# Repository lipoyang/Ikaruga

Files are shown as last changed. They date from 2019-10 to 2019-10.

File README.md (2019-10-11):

# 斑鳩ボード
## 概要
斑鳩ボードは、Nordic nRF52832搭載のBLEマイコンボードです。 

## 仕様
* BLEマイコンnRF52832搭載 (Bluetooth 4.2 / ARM Cortex-M4F)
* 技適取得済みnRF52832モジュール Liard BL652を使用
* Arduino Pro Miniピン互換 (GR-KURUMIやGR-CITRUSとも共通)
* nRF52-DKの開発環境（mbedやnRF5 SDK）で開発
* nRF52-DK や BLE Nano V2のDAPLinkボードをアダプタとして使う
* 300mAのLDO、3色のLED、32.768kHzサブクロック、リセットスイッチを搭載

## ピン配置
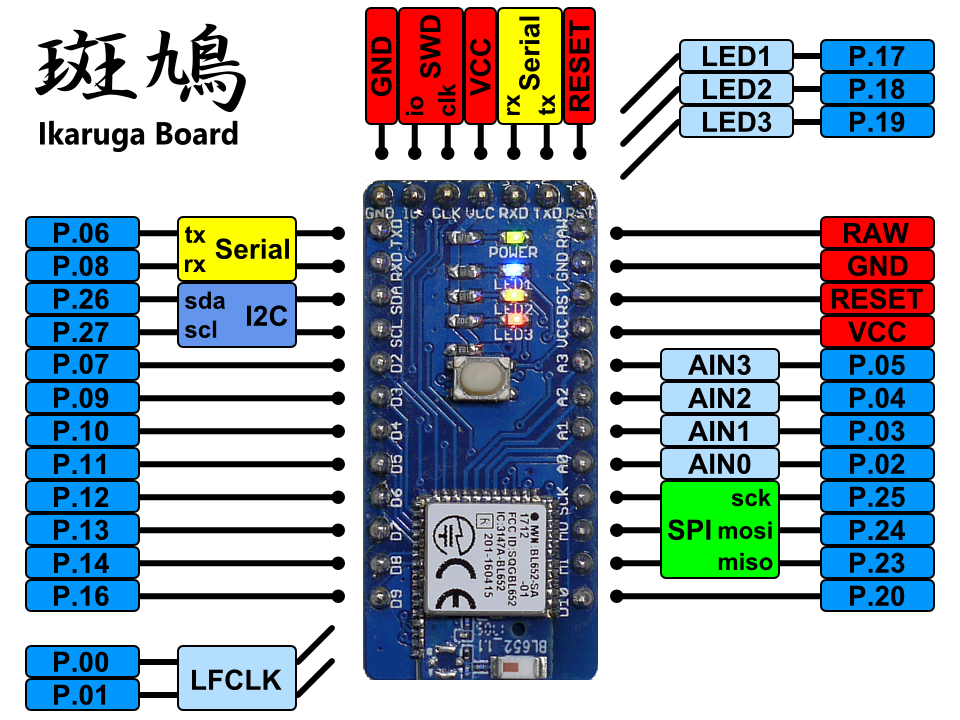
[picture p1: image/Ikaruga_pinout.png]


## 開発環境 (mbed)
* mbed Compiperのプラットフォーム選択でNordic nRF52-DKを選びます。
* BLE Nano V2のDAPLinkボードを使う場合、斑鳩を下図ように結線します。
* あとは、ふつうにmbedの要領で開発します。
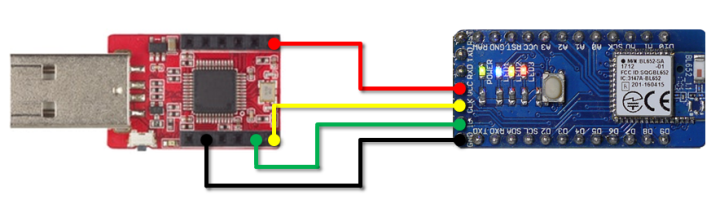
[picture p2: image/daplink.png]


## nRF52-DKをアダプタに使う場合
最低限、結線が必要なのは以下の4本です。

* GND DETECT　→　ターゲットのGNDに接続
* VTG　→　ターゲットの電源電圧(VDD_nRF)に接続
* SWD CLK　→　ターゲットのSWDCLKに接続
* SWD IO　→　ターゲットのSWDIOに接続

加えて、nRF52-DKボードから斑鳩ボードに給電する場合には以下の2本を結線します。

* GND　→　ターゲットのGNDに接続
* VDD　→　ターゲットの電源電圧(VDD_nRF)に接続
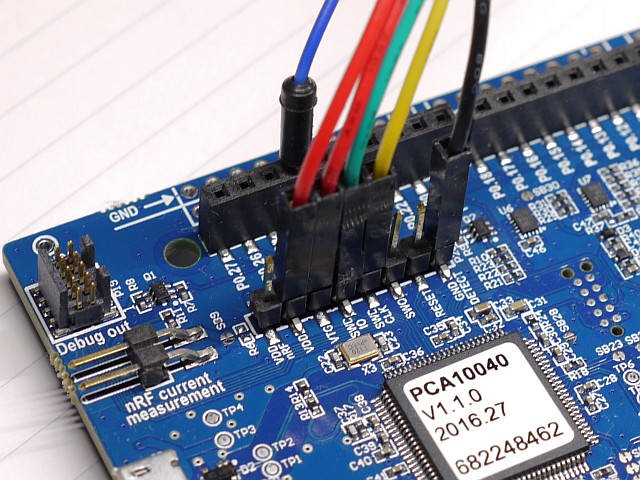
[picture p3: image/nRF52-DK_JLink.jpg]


## Ｌチカ (mbed)
```C
#include "mbed.h"

DigitalOut myled1(LED1); // Blue
DigitalOut myled2(LED2); // Yellow
DigitalOut myled3(LED3); // Red

int main() {
    while(1) {
        myled1 = 1;
        wait(0.5);
        myled2 = 1;
        wait(0.5);
        myled3 = 1;
        wait(0.5);
        myled1 = 0;
        wait(0.5);
        myled2 = 0;
        wait(0.5);
        myled3 = 0;
        wait(0.5);
    }
}
```

## ファイル一覧
* hard/Ikaruga/
	* Ikaruga.sch/brd: 回路/基板設計データ(Eagle形式)
	* Ikaruta.pdf: 回路図(PDF)
	* Ikaruga_BOM.xlsx: BOMリスト(Excel形式)
	* Ikaruga.GBL/GBO/GBP/GBS/GML/GTL/GTO/GTP/GTS/TXT: ガーバデータ
* LICENSE: Apache Licence 2.0です。
	* ただし、回路/基板設計は、Creative Commons Attribution Share-Alike 3.0です。
* README.md これ

## 注意
「斑鳩」は「いかるが」と読みます。  
聖徳太子と法隆寺で有名です。難読地名とか言わないでください。

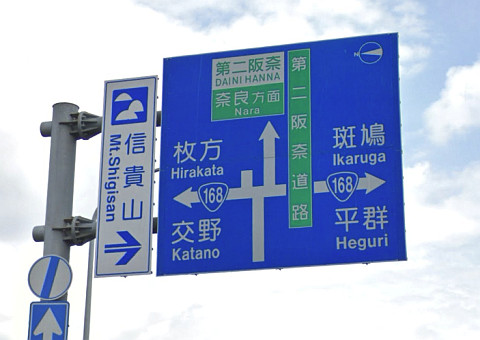
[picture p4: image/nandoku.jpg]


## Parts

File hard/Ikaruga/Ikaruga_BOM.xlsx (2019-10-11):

Ikaruga Board BOM
No | Reference | Part Number | Vender | Description | DNP | Qty | Unit Price | Price | Lot Size | Supplier | Supplier Code
1 | C1 | 10u(3216) | (generic) | 3216型 |  | 1 | 25 | 25 | 10 | 秋月 | P-06462
2 | C2 | 0.1u(1608) | (generic) | 1608型 |  | 1 | 0.325 | 0.325 | 4000 | 秋月 | P-01299
3 | C3 | 47u(3216) | (generic) | 3216型 |  | 1 | 30 | 30 | 10 | 秋月 | P-06040
4 | C4,5 | 12pF(1608) | (generic) | 1608型 |  | 2 | 1.8 | 3.6 | 100 | 秋月 | P-05521
5 | CN1,2 | - | (generic) | 2.54mmピッチ 12ピン×1列 ピンヘッダ | DNP | 0 | 0 | 0 | 1 | 共立 | -
6 | CN3 | - | (generic) | 2.54mmピッチ 7ピン×1列 ピンヘッダ | DNP | 0 | 0 | 0 | 2 | 共立 | -
7 | D1 | SS2040FL | PANJIT | ショットキーバリアダイオード 40V2A |  | 1 | 15 | 15 | 20 | 秋月 | I-02073
8 | LED1 | OSBL1608 | OptoSupply | 1608型 BLUE |  | 1 | 10 | 10 | 20 | 秋月 | I-03982
9 | LED2 | OSYL1608 | OptoSupply | 1608型 YELLOW |  | 1 | 10 | 10 | 20 | 秋月 | I-03984
10 | LED3 | OSHR1608 | OptoSupply | 1608型 RED |  | 1 | 10 | 10 | 20 | 秋月 | I-03978
11 | LED4 | OSYG1608 | OptoSupply | 1608型 GREEN |  | 1 | 10 | 10 | 20 | 秋月 | I-03980
12 | R1 | 470(1608) | (generic) | 1608型 |  | 1 | 0.2 | 0.2 | 2500 | 秋月 | R-06471
13 | R2,3 | 680(1608) | (generic) | 1608型 |  | 2 | 2.48 | 4.96 | 100 | RS | 391-5258
14 | R4 | 1k(1608) | (generic) | 1608型 |  | 1 | 0.2 | 0.2 | 2500 | 秋月 | R-06102
15 | R5 | 10k(1608) | (generic) | 1608型、±0.1% |  | 1 | 0.2 | 0.2 | 2500 | 秋月 | R-06103
16 | SW1 | SKRPACE010 | ALPS | 表面実装タクトスイッチ |  | 1 | 20 | 20 | 5 | 秋月 | P-06185
17 | U1 | MCP1824-3302E/OT | Microchip | LDO 3.3V 300mA SOT-23 5ピン |  | 1 | 57.2 | 57.2 | 1 | RS | 669-5011
18 | U2 | BL652-SA | Laird | nRF52832搭載 BLEマイコンモジュール |  | 1 | 905 | 905 | 1 | Digi-Key | BL652-SA-01-CT-ND
19 | X1 | FC-135 32.768kHz | Epson | 水晶発振子 32.768kHz |  | 1 | 40 | 40 | 5 | 秋月 | P-07195
20 | - | - | Elecrow | 基板 |  | 1 | 262.4 | 262.4 | 10 | Elecrow | -
 |  |  |  |  |  |  | Total | 1404.085

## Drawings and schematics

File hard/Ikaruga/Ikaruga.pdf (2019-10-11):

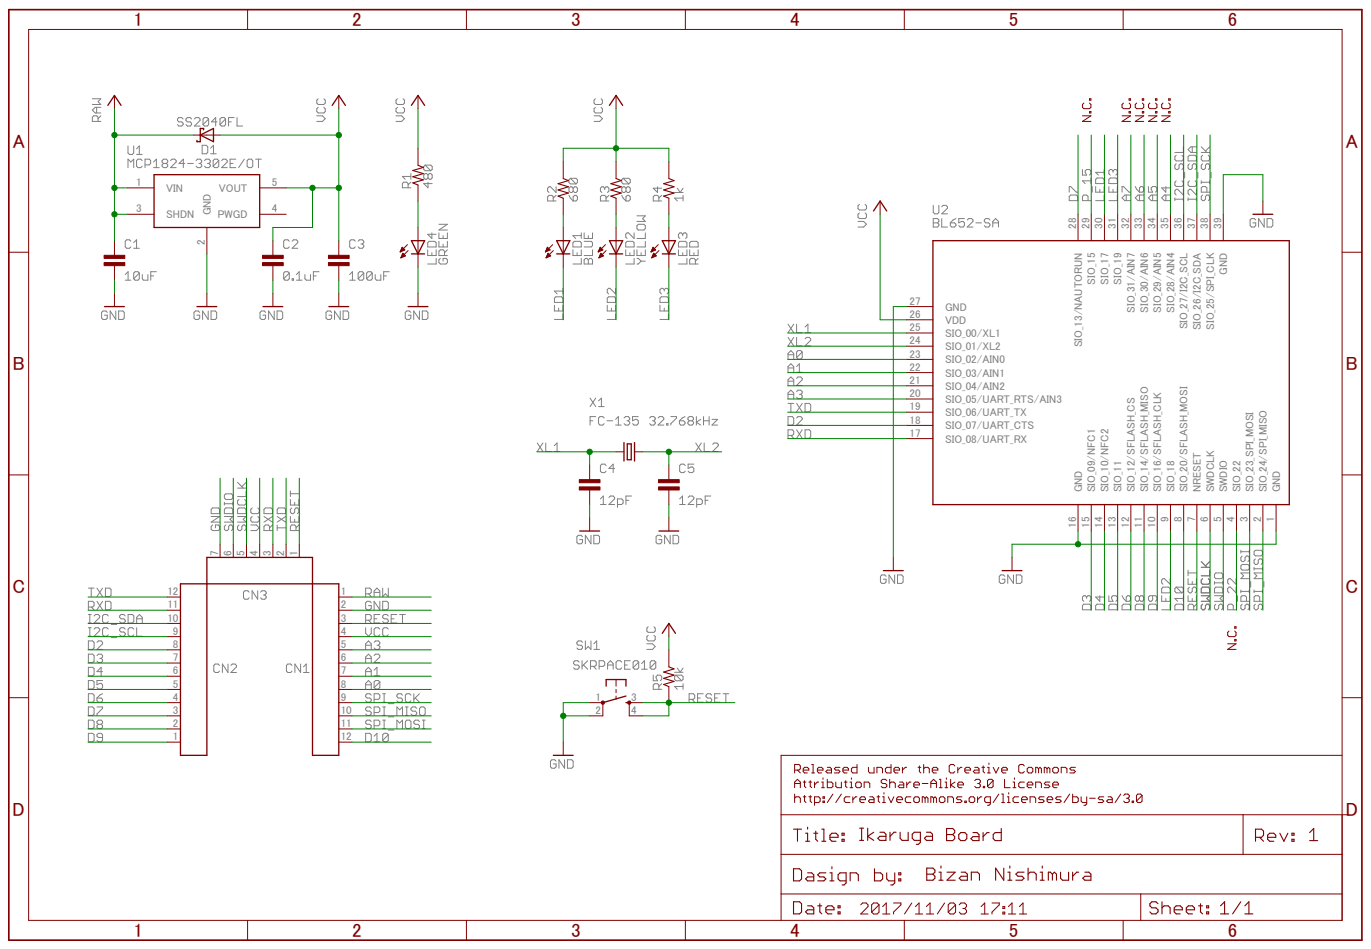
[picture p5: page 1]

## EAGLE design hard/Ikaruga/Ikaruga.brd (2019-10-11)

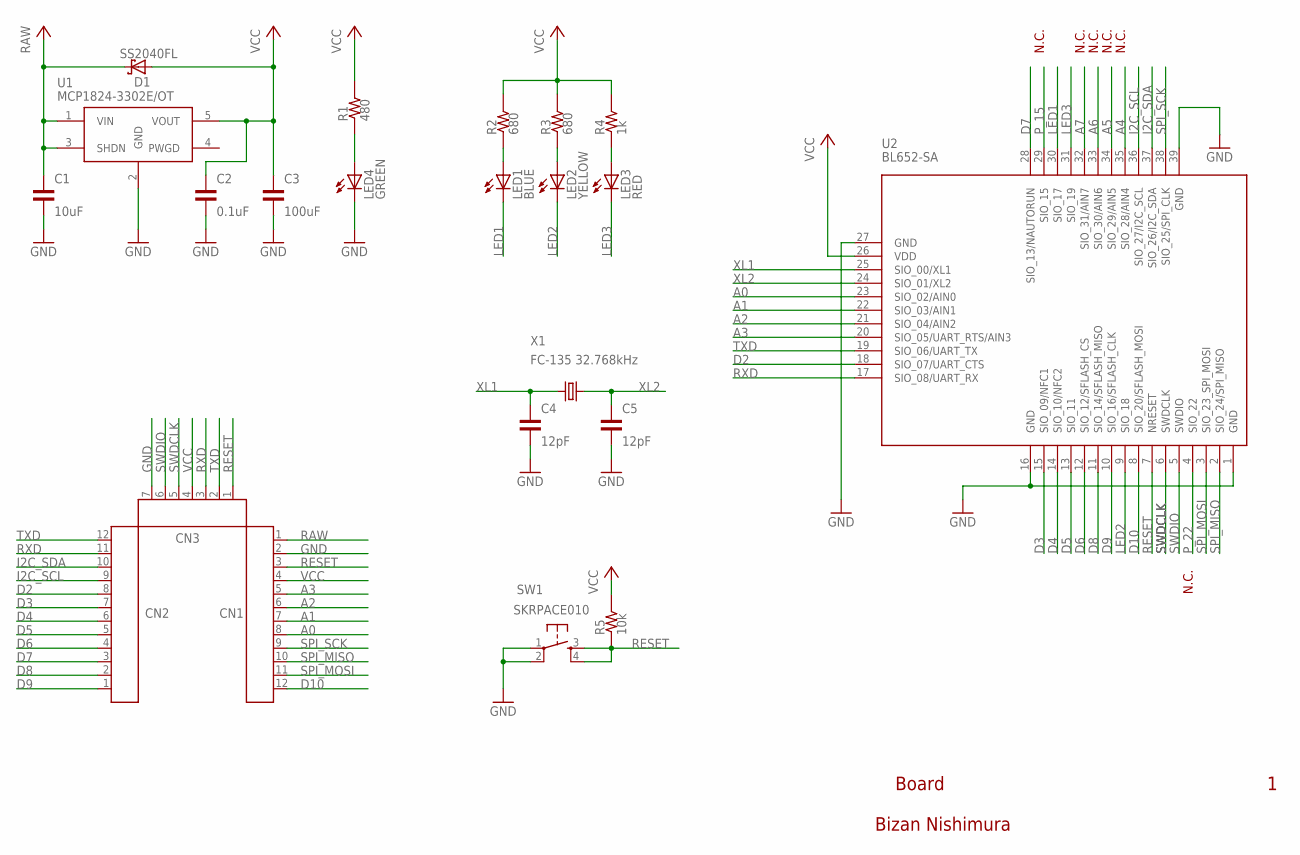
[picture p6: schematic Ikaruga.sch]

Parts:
C1: 10uF; CP3216
C2: 0.1uF; CP1608
C3: 100uF; CP3216
C4, C5: 12pF; CP1608
CN1, CN2: PINHD-1X12-NO-LINE; 1X12-NO-LINE
CN3: PINHD-1X7-NO-LINE; 1X07-NO-LINE
D1: SS2040FL; SOD123
LED1: BLUE; LED1608
LED2: YELLOW; LED1608
LED3: RED; LED1608
LED4: GREEN; LED1608
R1: 480; CP1608
R2, R3: 680; CP1608
R4: 1k; CP1608
R5: 10k; CP1608
SW1: SKRPACE010
U1: MCP1824-3302E/OT; SOT-23-5
U2: BL652-SA
X1: FC-135 32.768kHz; FC-135

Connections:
A0: CN1.8, U2.23 (SIO_02/AIN0)
A1: CN1.7, U2.22 (SIO_03/AIN1)
A2: CN1.6, U2.21 (SIO_04/AIN2)
A3: CN1.5, U2.20 (SIO_05/UART_RTS/AIN3)
A4: U2.35 (SIO_28/AIN4)
A5: U2.34 (SIO_29/AIN5)
A6: U2.33 (SIO_30/AIN6)
A7: U2.32 (SIO_31/AIN7)
D2: CN2.8, U2.18 (SIO_07/UART_CTS)
D3: CN2.7, U2.15 (SIO_09/NFC1)
D4: CN2.6, U2.14 (SIO_10/NFC2)
D5: CN2.5, U2.13 (SIO_11)
D6: CN2.4, U2.12 (SIO_12/SFLASH_CS)
D7: CN2.3, U2.28 (SIO_13/NAUTORUN)
D8: CN2.2, U2.11 (SIO_14/SFLASH_MISO)
D9: CN2.1, U2.10 (SIO_16/SFLASH_CLK)
D10: CN1.12, U2.8 (SIO_20/SFLASH_MOSI)
GND: C1.SMD2 (PIN2), C2.SMD2 (PIN2), C3.SMD2 (PIN2), C4.SMD2 (PIN2), C5.SMD2 (PIN2), CN1.2, CN3.7, LED4.C, SW1.1, SW1.2, U1.2 (GND), U2.1 (GND), U2.16 (GND), U2.27 (GND), U2.39 (GND)
I2C_SCL: CN2.9, U2.36 (SIO_27/I2C_SCL)
I2C_SDA: CN2.10, U2.37 (SIO_26/I2C_SDA)
LED1: LED1.C, U2.30 (SIO_17)
LED2: LED2.C, U2.9 (SIO_18)
LED3: LED3.C, U2.31 (SIO_19)
unnamed: LED4.A, R1.SMD1 (PIN1)
unnamed: LED1.A, R2.SMD1 (PIN1)
unnamed: LED2.A, R3.SMD1 (PIN1)
unnamed: LED3.A, R4.SMD1 (PIN1)
P_15: U2.29 (SIO_15)
P_22: U2.4 (SIO_22)
RAW: C1.SMD1 (PIN1), CN1.1, D1.C, U1.1 (VIN), U1.3 (SHDN)
RESET: CN1.3, CN3.1, R5.SMD1 (PIN1), SW1.3, SW1.4, U2.7 (NRESET)
RXD: CN2.11, CN3.3, U2.17 (SIO_08/UART_RX)
SPI_MISO: CN1.10, U2.2 (SIO_24/SPI_MISO)
SPI_MOSI: CN1.11, U2.3 (SIO_23_SPI_MOSI)
SPI_SCK: CN1.9, U2.38 (SIO_25/SPI_CLK)
SWDCLK: CN3.5, U2.6 (SWDCLK)
SWDIO: CN3.6, U2.5 (SWDIO)
TXD: CN2.12, CN3.2, U2.19 (SIO_06/UART_TX)
VCC: C2.SMD1 (PIN1), C3.SMD1 (PIN1), CN1.4, CN3.4, D1.A, R1.SMD2 (PIN2), R2.SMD2 (PIN2), R3.SMD2 (PIN2), R4.SMD2 (PIN2), R5.SMD2 (PIN2), U1.5 (VOUT), U2.26 (VDD)
XL1: C4.SMD1 (PIN1), U2.25 (SIO_00/XL1), X1.1
XL2: C5.SMD1 (PIN1), U2.24 (SIO_01/XL2), X1.2

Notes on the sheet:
Bizan Nishimura
Board
N.C.

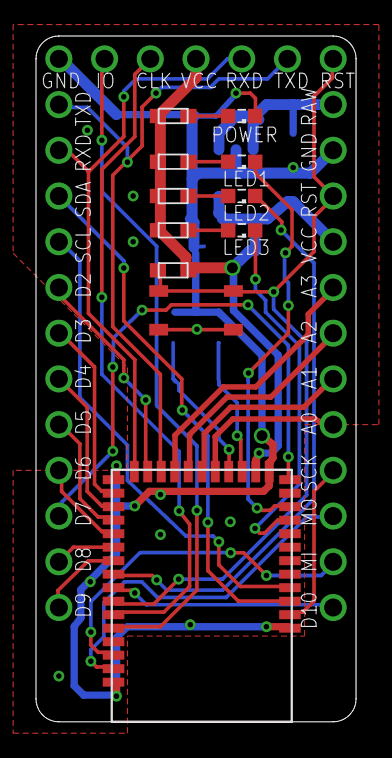
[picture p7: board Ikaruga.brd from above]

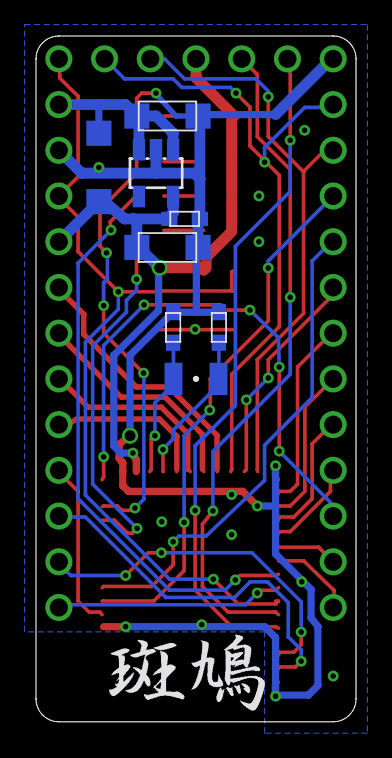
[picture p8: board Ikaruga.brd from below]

Board: 2 copper layers, 17.8 x 38.1 mm, 23 parts (8 on the bottom side), 35 nets.

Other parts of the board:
U$1: IKARUGA_B

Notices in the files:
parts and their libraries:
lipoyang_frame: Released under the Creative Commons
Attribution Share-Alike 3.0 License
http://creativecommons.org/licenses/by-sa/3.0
